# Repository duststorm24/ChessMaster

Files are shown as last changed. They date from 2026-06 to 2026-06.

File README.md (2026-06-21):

# ChessMaster

ChessMaster is a full-stack robotic chess project: a Raspberry Pi camera app for board/piece recognition, a browser-based 3D inverse-kinematics UI for a physical robotic arm, Arduino/CNC-shield firmware for the motors, and CAD files for the printed arm assembly.

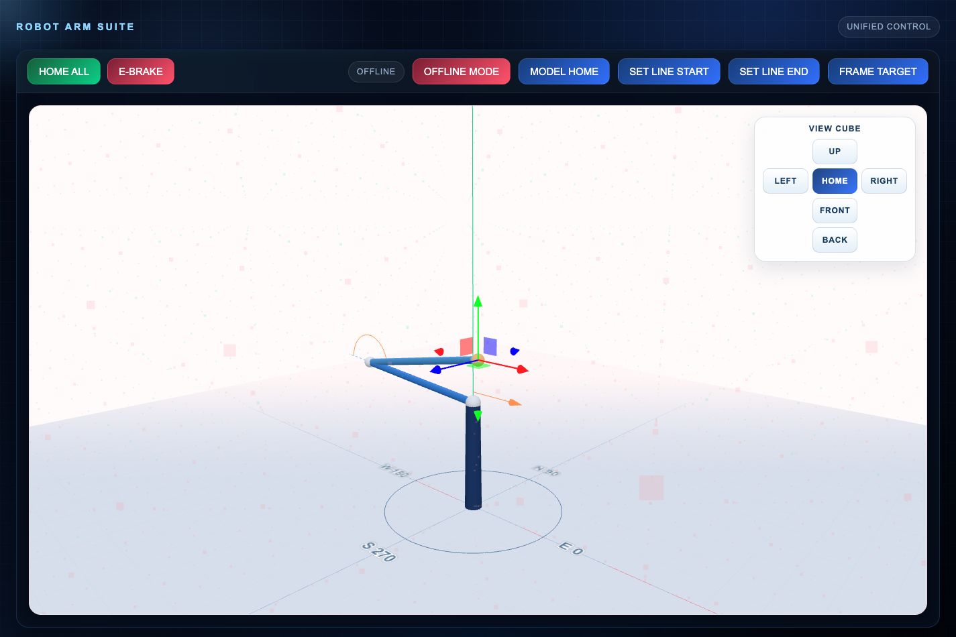
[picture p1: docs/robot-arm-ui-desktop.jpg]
Robot arm 3D UI


<p align="center">
  Robot arm following the 3D inverse-kinematics UI target
</p>

## What This Shows

- **3D robotic arm control:** `apps/robot-web` renders a Three.js arm model with draggable target controls, forward/inverse kinematics, saved positions, and Cartesian line moves.
- **Hardware control path:** the robot UI converts reachable 3D targets into axis step targets and sends them to an Arduino arm controller over serial.
- **Chess vision pipeline:** `apps/vision` runs a Raspberry Pi camera web UI with OpenCV board detection, square crops, calibration, labels, FEN generation, and starter piece-recognition tools.
- **Embedded firmware:** `firmware` contains Arduino/CNC Shield sketches for homing, limit switches, coordinated stepper motion, and serial commands.
- **Physical design:** `hardware/cad` contains STL exports for the arm, base, claw, gears, and chess pieces.

## Project Layout

```text
apps/
  robot-web/      Main 3D IK robotic arm UI and movement API
  vision/         Raspberry Pi camera/CV chessboard app
  arm-ui/         Simpler direct axis/stepper control UI
  arm-test/       Arm test app and matching Arduino sketch
  chessbot-test/  Small chess/Stockfish experiments
firmware/         Arduino and CNC-shield sketches
hardware/cad/     Printable CAD/STL assets
models/           YOLO/model assets used by Pi-side experiments
scripts/          Standalone camera and YOLO stream scripts
data/             Non-secret calibration and saved-position examples
docs/             README images and supporting docs
```

## Main Apps

### 3D Robot Arm UI

```sh
cd apps/robot-web
python3 -m venv .venv
source .venv/bin/activate
pip install -r requirements.txt
python app.py
```

Open `http://localhost:5000`.

The UI can run without the robot attached in offline mode. Online robot movement expects an Arduino-compatible controller at `/dev/ttyACM0`.

### Chess Vision Camera App

```sh
cd apps/vision
python3 -m venv .venv
source .venv/bin/activate
pip install -r requirements.txt
python app.py
```

Open `http://localhost:8000`.

The camera app is intended for Raspberry Pi hardware with a supported camera module. See `apps/vision/README.md` for Pi setup and service installation notes.

## Hardware Notes

The robot control code was built around a Raspberry Pi, Arduino Uno/CNC Shield V3, A4988 stepper drivers, limit switches, and a custom 3-axis printed arm. The web UI and CV app can be inspected without hardware, but real movement/camera capture require the Pi and controller connections.

## Safety And Privacy

This public repo excludes local virtual environments, generated camera captures, logs, caches, `.env` files, and oversized CAD source archives. Non-secret calibration examples and saved robot positions are included so the control and vision workflows are understandable.

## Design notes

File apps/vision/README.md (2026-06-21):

# Chess Vision Camera App

Small Raspberry Pi 5 camera viewer for the first chess-vision milestone.

## Hardware Check

Power the Pi down before connecting the CSI ribbon cable:

```bash
ssh <pi-user>@chesspi.local
cd ~/ChessMaster/apps/vision
./shutdown_for_camera_install.sh --confirm
```

Unplug power, connect the camera to `CAM/DISP0`, reconnect power, then SSH back in.

Verify the camera:

```bash
rpicam-hello --list-cameras
rpicam-still -n -t 2s -o ~/camera-test.jpg
```

Or run the bundled diagnostic check:

```bash
cd ~/ChessMaster/apps/vision
./post_boot_camera_check.sh
```

If the camera is plugged in and still not detected, switch the Pi back to camera auto-detection and reboot:

```bash
cd ~/ChessMaster/apps/vision
./set_camera_autodetect.sh
sudo reboot
```

## Run The Web UI

On the Pi:

```bash
cd ~/ChessMaster/apps/vision
./start.sh
```

To install the web UI as a boot-time service:

```bash
cd ~/ChessMaster/apps/vision
./install_service.sh
```

From your laptop, open:

```text
http://chesspi.local:8000
```

To stop the background server:

```bash
cd ~/ChessMaster/apps/vision
./stop.sh
```

To remove the boot-time service:

```bash
cd ~/ChessMaster/apps/vision
./uninstall_service.sh
```

The UI streams the camera, includes a toggleable chessboard grid overlay, shows camera diagnostics, and saves snapshots into `captures/`. Use the calibration sliders to line the grid up with the board, or point the camera at an empty board and click `Save + detect board` to save a frame, let OpenCV estimate the grid, refresh square crops, and save an annotated board-detection debug image. Set `White at bottom` to match the camera's view. The piece-position editor lets you paint pieces onto squares, save a FEN-backed position, load the standard starting position, or clear the board. The saved-captures gallery lists snapshot images and metadata from the browser, can load saved or predicted labels back into the board painter, apply the current board-painter labels to an existing snapshot, save a labeled training sample in one step, detect the board grid, export each full-board snapshot into 64 labeled square crops under `captures/square-crops/`, and analyze those crops for brightness, contrast, and edge density. The dataset panel plus `/dataset` and `/dataset.csv` endpoints roll analyzed square crops into training-style rows with labels and features. `Train occupancy` builds a simple occupied-vs-empty baseline model, while `Train pieces` builds a starter nearest-centroid image classifier from labeled square crops. `Evaluate pieces` reports training accuracy and leave-one-out accuracy for the labeled crop dataset. `Predict pieces` writes a predicted piece map and FEN back to the capture manifest. `Recognize position` refreshes square crops, predicts pieces, and returns a confidence summary; `Save + recognize` does the same for the live camera frame. Snapshots include a JSON sidecar with the saved calibration, all 64 square rectangles, the saved piece map, and FEN so later chessboard and piece-detection code can map image pixels to squares.

The camera controls include three view modes: `HD 16:9` is a fast cropped preview, `Full FOV` uses the full sensor at `2328 x 1748`, and `Max FOV` uses the full sensor at `4656 x 3496` with a slower 1 FPS stream. Focus controls support continuous autofocus, one-shot autofocus, autofocus range/speed, and manual lens position when the connected camera exposes those controls.

Useful endpoints:

```text
/health
/diagnostics
/readiness
/captures
/dataset
/dataset.csv
/model/occupancy
/model/piece
/model/piece/evaluate
/camera-settings
/focus/trigger
/calibration
/board-map
/position
/snapshot/detect-board
/snapshot/recognize-position
/captures/<snapshot>.jpg/labels
/captures/<snapshot>.jpg/save-labeled-sample
/captures/<snapshot>.jpg/detect-board
/captures/<snapshot>.jpg/predict-pieces
/captures/<snapshot>.jpg/recognize-position
```

`/readiness` rolls camera detection, boot config, captures, calibration, dataset rows, labels, and models into one checklist. If the camera is connected but still not detected, check the boot-config gate and consider `./set_camera_autodetect.sh`.

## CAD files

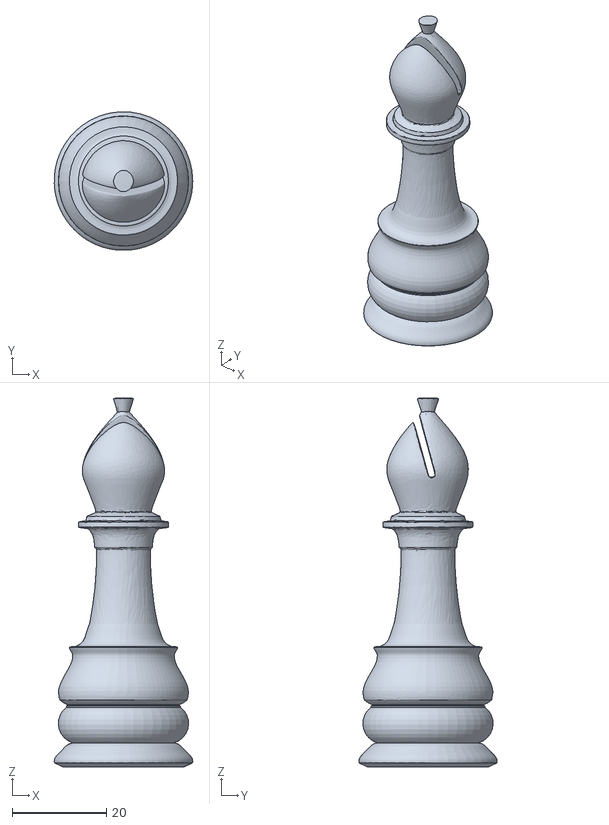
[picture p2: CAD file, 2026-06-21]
hardware/cad/original-cad-files/Chess Pieces/Bishop.stl
29.4 x 29.4 x 78.4

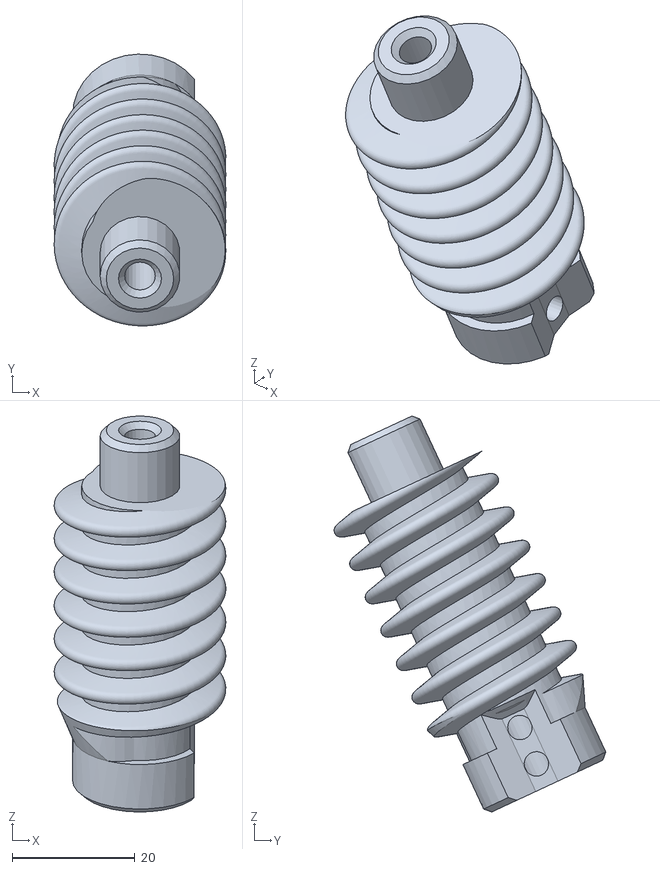
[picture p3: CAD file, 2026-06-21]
hardware/cad/original-cad-files/V3/Chess Playing Robot.stl
28.0 x 44.3 x 64.6

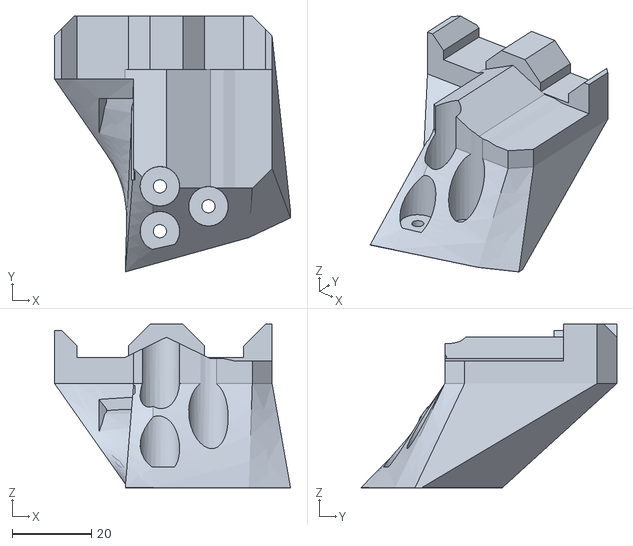
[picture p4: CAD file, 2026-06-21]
hardware/cad/v3-cad-files/V4 Claw Extension.stl
59.6 x 64.7 x 41.4

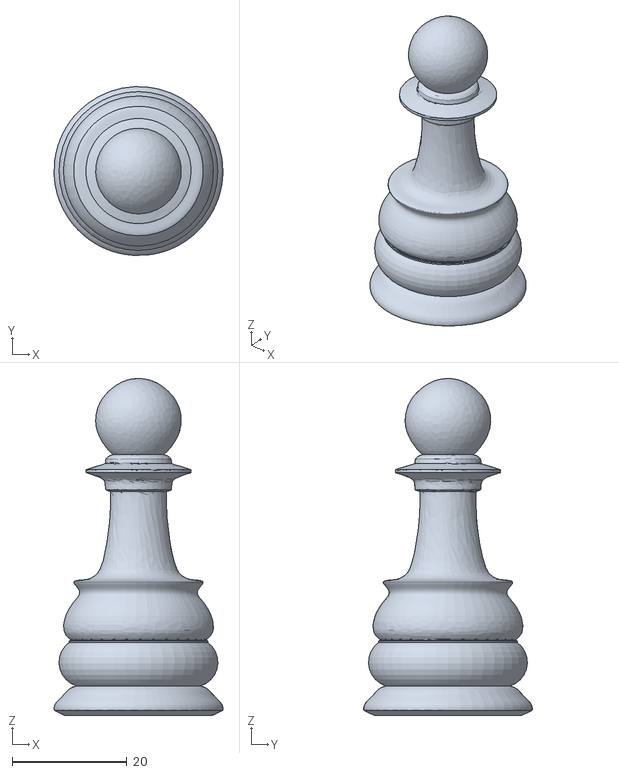
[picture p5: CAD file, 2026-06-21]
hardware/cad/original-cad-files/Chess Pieces/Pawn.stl
29.4 x 29.4 x 58.7

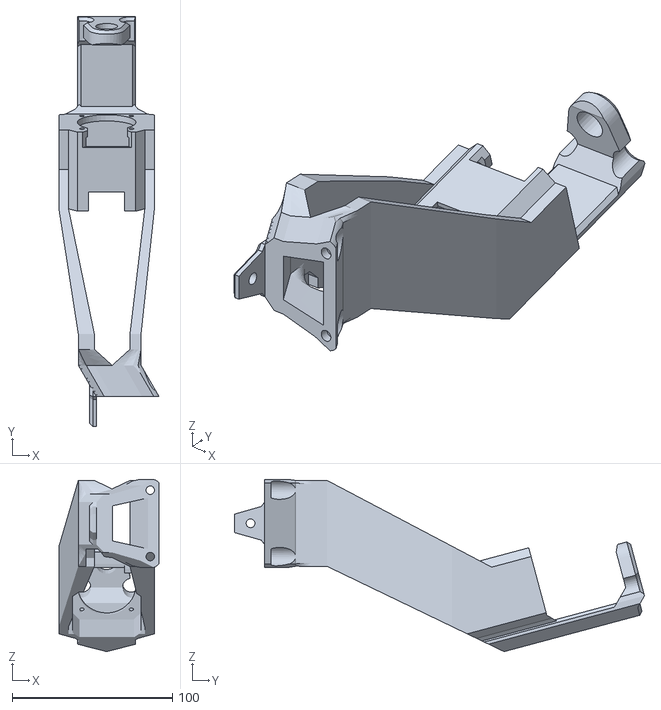
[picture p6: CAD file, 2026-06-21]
hardware/cad/v3-cad-files/Arm 1 Test.stl
62.5 x 255.8 x 107.5

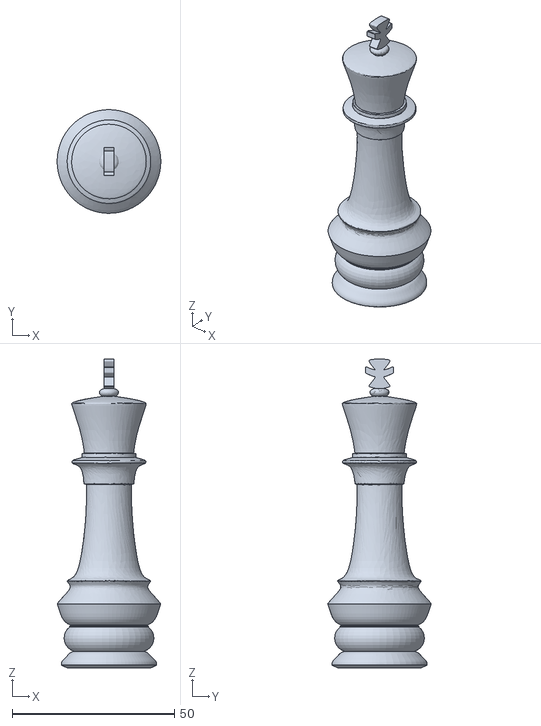
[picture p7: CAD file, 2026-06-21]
hardware/cad/original-cad-files/Chess Pieces/King2.stl
32.0 x 32.0 x 95.3

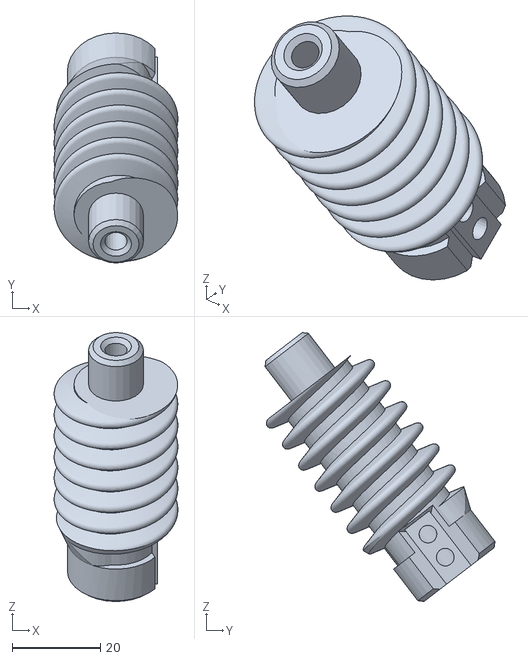
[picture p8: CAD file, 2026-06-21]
hardware/cad/v3-cad-files/V4 Worm Gear.stl
28.0 x 52.0 x 60.8

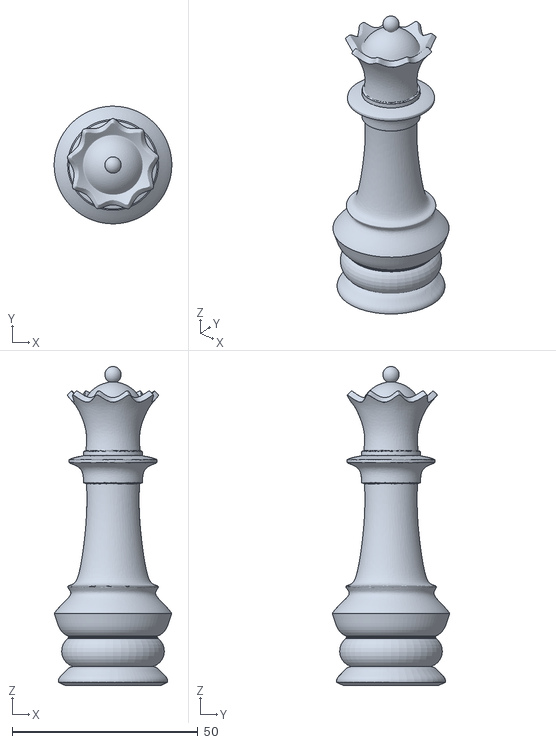
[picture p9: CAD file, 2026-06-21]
hardware/cad/original-cad-files/Chess Pieces/Queen.stl
31.7 x 31.7 x 85.9

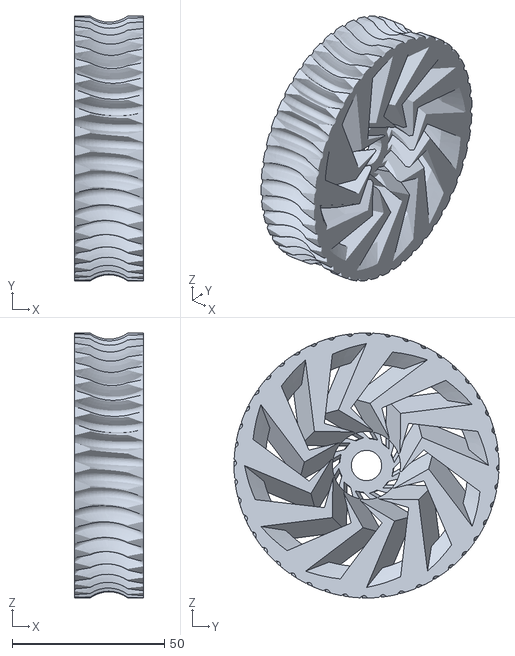
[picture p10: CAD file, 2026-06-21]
hardware/cad/v3-cad-files/Worm Wheel 2.stl
22.7 x 87.0 x 87.0

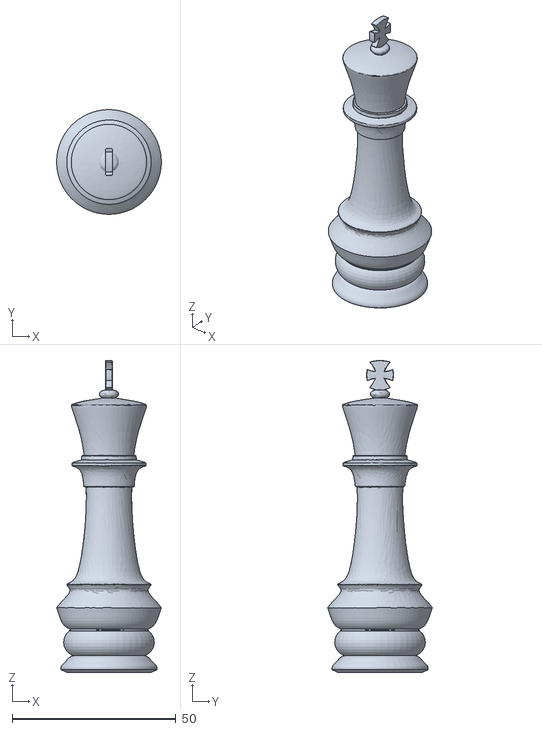
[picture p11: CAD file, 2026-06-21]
hardware/cad/original-cad-files/Chess Pieces/King.stl
32.0 x 32.0 x 95.2

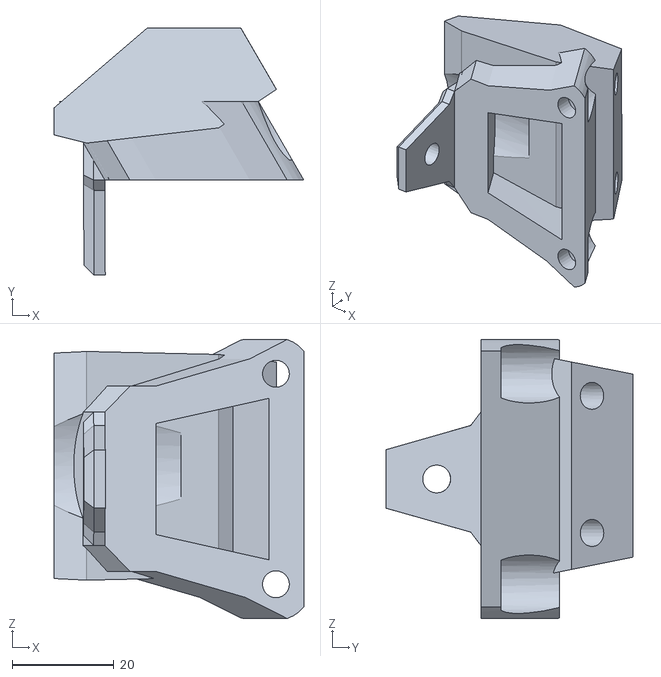
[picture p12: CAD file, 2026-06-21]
hardware/cad/v3-cad-files/Test Adapter.stl
49.2 x 48.7 x 54.9

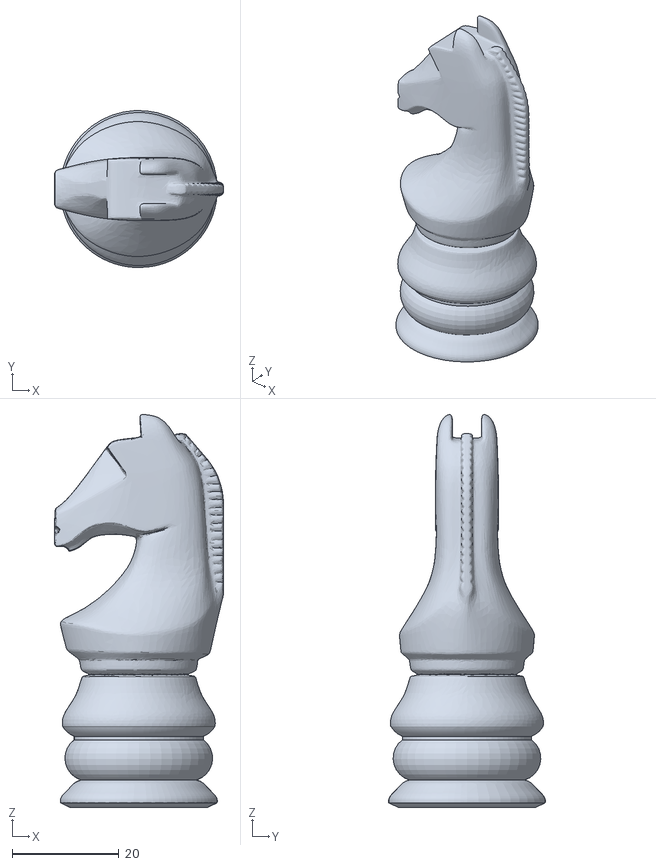
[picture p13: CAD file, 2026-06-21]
hardware/cad/original-cad-files/Chess Pieces/Knight.stl
31.8 x 29.4 x 73.6

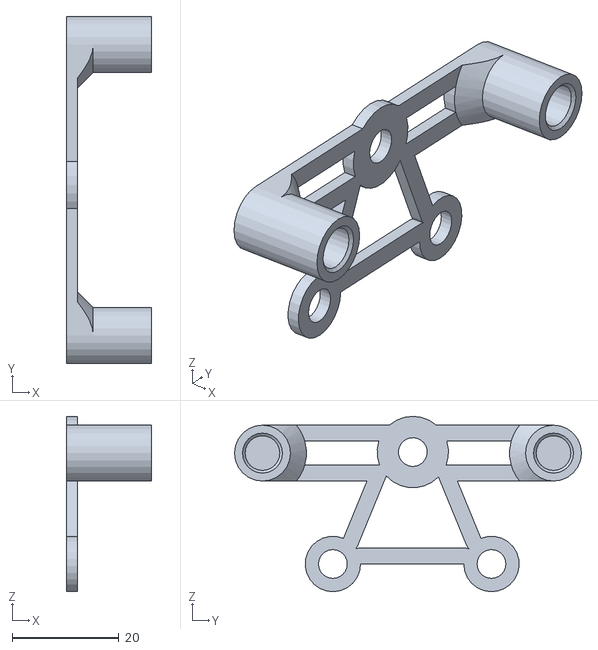
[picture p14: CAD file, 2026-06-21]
hardware/cad/v3-cad-files/Buck Mount 2.stl
15.9 x 65.1 x 32.9

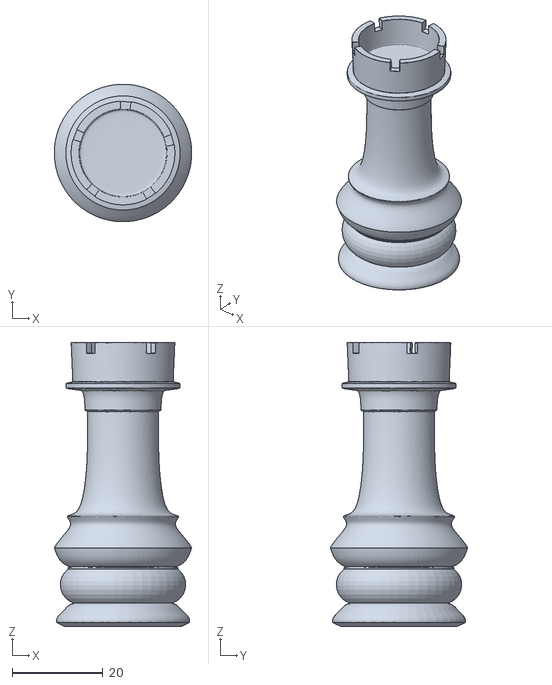
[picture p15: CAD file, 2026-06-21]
hardware/cad/original-cad-files/Chess Pieces/Rook.stl
30.3 x 30.3 x 62.7

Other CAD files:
hardware/cad/v3-cad-files/Worm Wheel.stl
hardware/cad/v3-cad-files/V4 Base.stl
hardware/cad/v3-cad-files/Base Plate V3.stl
hardware/cad/v3-cad-files/Large Claw V3.stl
hardware/cad/original-cad-files/V2/5v Pi Buck Holder.stl
hardware/cad/original-cad-files/V2/ARM1 SMALL.stl
hardware/cad/original-cad-files/V2/Arm 1 Base Backplate.stl
hardware/cad/original-cad-files/V2/Arm 1 Base.stl
hardware/cad/original-cad-files/V2/Arm 1 Stepper Support.stl
hardware/cad/original-cad-files/V2/Arm 1.stl
hardware/cad/original-cad-files/V2/Arm 2 and Stabilizers/Arm 2 Coupler.stl
hardware/cad/original-cad-files/V2/Arm 2 and Stabilizers/Arm 2 Part 1.stl
hardware/cad/original-cad-files/V2/Arm 2 and Stabilizers/Arm 2 Part 2.stl
hardware/cad/original-cad-files/V2/Arm 2 and Stabilizers/Chess Playing Robot.stl
hardware/cad/original-cad-files/V2/Arm 2 and Stabilizers/Coupler.stl
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

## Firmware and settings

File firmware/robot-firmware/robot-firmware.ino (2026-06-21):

#include <AccelStepper.h>

// CNC Shield V3 standard pins for X/Y/Z
#define X_STEP_PIN 2
#define Y_STEP_PIN 3
#define Z_STEP_PIN 4
#define X_DIR_PIN  5
#define Y_DIR_PIN  6
#define Z_DIR_PIN  7
#define ENABLE_PIN 8
#define Z_LIMIT_PIN 11
#define Y_LIMIT_PIN 10
#define X_LIMIT_PIN 9
#define Z_MAX_DISTANCE_FROM_HOME 10000L
#define X_MAX_DISTANCE_FROM_HOME 9000L
#define Y_MAX_DISTANCE_FROM_HOME 9200L
#define X_ACCELERATION 2500.0
#define Y_ACCELERATION 2500.0
#define Z_ACCELERATION 2500.0
#define X_HOME_SPEED 1200
#define Y_HOME_SPEED 1200
#define Z_HOME_SPEED 400
#define MIN_COMMAND_SPEED 25
#define MAX_COMMAND_SPEED 3000
#define KEEP_DRIVERS_ENABLED 0

// A axis on D12/D13 for custom independent control
#define A_STEP_PIN 12
#define A_DIR_PIN  13

AccelStepper stepperX(AccelStepper::DRIVER, X_STEP_PIN, X_DIR_PIN);
AccelStepper stepperY(AccelStepper::DRIVER, Y_STEP_PIN, Y_DIR_PIN);
AccelStepper stepperZ(AccelStepper::DRIVER, Z_STEP_PIN, Z_DIR_PIN);
AccelStepper stepperA(AccelStepper::DRIVER, A_STEP_PIN, A_DIR_PIN);

bool activeX = false;
bool activeY = false;
bool activeZ = false;
bool activeA = false;
bool stepModeX = false;
bool stepModeY = false;
bool stepModeZ = false;
bool stepModeA = false;
bool accelModeX = false;
bool accelModeY = false;
bool accelModeZ = false;
bool homingZ = false;
bool zHomed = false;
bool yHomed = false;
bool xHomed = false;

unsigned long stopTimeX = 0;
unsigned long stopTimeY = 0;
unsigned long stopTimeZ = 0;
unsigned long stopTimeA = 0;

String inputLine = "";

void setDriversEnabled(bool enabled) {
  if (!enabled && KEEP_DRIVERS_ENABLED) {
    enabled = true;
  }
  digitalWrite(ENABLE_PIN, enabled ? LOW : HIGH);
}

bool isZLimitPressed();
bool isYLimitPressed();
bool isXLimitPressed();
long getXDistanceFromHome();
long getYDistanceFromHome();
long getZDistanceFromHome();
bool isYAtOrPastMaxDistance();
bool isZAtOrPastMaxDistance();
int resolveCommandSpeed(int requestedSpeed, int fallbackSpeed);
void startHoming(char axis, int speed);
void startHomingAll(int speedX, int speedY, int speedZ);
void processCommand(String cmd);
bool startAxis(char axis, int speed, int direction, int duration);
void stopAxis(String axis);
void readSerialCommands();
void runMotor(AccelStepper &stepper, bool &active, unsigned long &stopTime);
bool startAxisSteps(char axis, long steps, int direction, int speed);

void setup() {
  Serial.begin(115200);

  pinMode(ENABLE_PIN, OUTPUT);
  setDriversEnabled(KEEP_DRIVERS_ENABLED);
  pinMode(Z_LIMIT_PIN, INPUT_PULLUP);
  pinMode(Y_LIMIT_PIN, INPUT_PULLUP);
  pinMode(X_LIMIT_PIN, INPUT_PULLUP);

  if (isZLimitPressed()) {
    stepperZ.setCurrentPosition(0);
    zHomed = true;
  }
  if (isYLimitPressed()) {
    stepperY.setCurrentPosition(0);
    yHomed = true;
  }
  if (isXLimitPressed()) {
    stepperX.setCurrentPosition(0);
    xHomed = true;
  }

  stepperX.setMaxSpeed(3000);
  stepperY.setMaxSpeed(3000);
  stepperZ.setMaxSpeed(3000);
  stepperA.setMaxSpeed(3000);

  stepperX.setAcceleration(X_ACCELERATION);
  stepperY.setAcceleration(Y_ACCELERATION);
  stepperZ.setAcceleration(Z_ACCELERATION);
  stepperA.setAcceleration(100000);

  stepperX.setSpeed(0);
  stepperY.setSpeed(0);
  stepperZ.setSpeed(0);
  stepperA.setSpeed(0);
}

void loop() {
  readSerialCommands();
  runMotor(stepperX, activeX, stopTimeX);
  runMotor(stepperY, activeY, stopTimeY);
  runMotor(stepperZ, activeZ, stopTimeZ);
  runMotor(stepperA, activeA, stopTimeA);
}

void runMotor(AccelStepper &stepper, bool &active, unsigned long &stopTime) {
  if (!active) {
    return;
  }

  bool isXAxis = (&stepper == &stepperX);
  bool isYAxis = (&stepper == &stepperY);
  bool isZAxis = (&stepper == &stepperZ);

  bool inStepMode = (&stepper == &stepperX && stepModeX) ||
                    (&stepper == &stepperY && stepModeY) ||
                    (&stepper == &stepperZ && stepModeZ) ||
                    (&stepper == &stepperA && stepModeA);
  bool inAccelModeX = isXAxis && accelModeX;
  bool inAccelModeY = isYAxis && accelModeY;
  bool inAccelModeZ = isZAxis && accelModeZ;

  long commandedDelta = 0;
  if (inAccelModeX || inAccelModeY || inAccelModeZ || inStepMode) {
    commandedDelta = stepper.distanceToGo();
  }

  bool movingXTowardHome = isXAxis && ((inAccelModeX || stepModeX) ? (commandedDelta < 0) : (stepper.speed() < 0));
  bool movingXAwayFromHome = isXAxis && ((inAccelModeX || stepModeX) ? (commandedDelta > 0) : (stepper.speed() > 0));
  bool movingYTowardHome = isYAxis && ((inAccelModeY || stepModeY) ? (commandedDelta > 0) : (stepper.speed() > 0));
  bool movingYAwayFromHome = isYAxis && ((inAccelModeY || stepModeY) ? (commandedDelta < 0) : (stepper.speed() < 0));
  bool movingZForward = isZAxis && ((inAccelModeZ || stepModeZ) ? (commandedDelta > 0) : (stepper.speed() > 0));
  bool movingZAwayFromHome = isZAxis && ((inAccelModeZ || stepModeZ) ? (commandedDelta < 0) : (stepper.speed() < 0));

  bool hitXLimit = isXAxis && movingXTowardHome && isXLimitPressed();
  bool hitXMaxDistance = isXAxis && movingXAwayFromHome && xHomed && (stepperX.currentPosition() >= X_MAX_DISTANCE_FROM_HOME);
  bool hitYLimit = isYAxis && movingYTowardHome && isYLimitPressed();
  bool hitYMaxDistance = isYAxis && movingYAwayFromHome && yHomed && (stepperY.currentPosition() <= -Y_MAX_DISTANCE_FROM_HOME);
  bool hitZLimit = isZAxis && movingZForward && isZLimitPressed();
  bool hitZMaxDistance = isZAxis && movingZAwayFromHome && zHomed && (stepperZ.currentPosition() <= -Z_MAX_DISTANCE_FROM_HOME);

  bool timedOut = !(isZAxis && homingZ) && !inStepMode && !inAccelModeX && !inAccelModeY && !inAccelModeZ && (millis() >= stopTime);
  bool reachedTarget = (inStepMode || inAccelModeX || inAccelModeY || inAccelModeZ) && (stepper.distanceToGo() == 0);

  if (hitXLimit) {
    stepper.stop();
    stepper.setSpeed(0);
    active = false;
    stepModeX = false;
    accelModeX = false;
    stepperX.setCurrentPosition(0);
    xHomed = true;

    if (!activeX && !activeY && !activeZ && !activeA) {
      setDriversEnabled(false);
    }
  } else if (hitXMaxDistance) {
    stepper.stop();
    stepper.setSpeed(0);
    active = false;
    stepModeX = false;
    accelModeX = false;
    stepperX.setCurrentPosition(X_MAX_DISTANCE_FROM_HOME);

    if (!activeX && !activeY && !activeZ && !activeA) {
      setDriversEnabled(false);
    }
  } else if (hitYLimit) {
    stepper.stop();
    stepper.setSpeed(0);
    active = false;
    stepModeY = false;
    accelModeY = false;
    stepperY.setCurrentPosition(0);
    yHomed = true;

    if (!activeX && !activeY && !activeZ && !activeA) {
      setDriversEnabled(false);
    }
  } else if (hitYMaxDistance) {
    stepper.stop();
    stepper.setSpeed(0);
    active = false;
    stepModeY = false;
    accelModeY = false;
    stepperY.setCurrentPosition(-Y_MAX_DISTANCE_FROM_HOME);

    if (!activeX && !activeY && !activeZ && !activeA) {
      setDriversEnabled(false);
    }
  } else if (hitZLimit) {
    stepper.stop();
    stepper.setSpeed(0);
    active = false;
    stepperZ.setCurrentPosition(0);
    zHomed = true;
    stepModeZ = false;
    accelModeZ = false;
    homingZ = false;

    if (!activeX && !activeY && !activeZ && !activeA) {
      setDriversEnabled(false);
    }
  } else if (hitZMaxDistance) {
    stepper.stop();
    stepper.setSpeed(0);
    active = false;
    homingZ = false;
    stepModeZ = false;
    accelModeZ = false;
    stepperZ.setCurrentPosition(-Z_MAX_DISTANCE_FROM_HOME);

    if (!activeX && !activeY && !activeZ && !activeA) {
      setDriversEnabled(false);
    }
  } else if (timedOut || reachedTarget) {
    stepper.stop();
    stepper.setSpeed(0);
    active = false;

    if (&stepper == &stepperX) {
      stepModeX = false;
      accelModeX = false;
    }
    if (&stepper == &stepperY) {
      stepModeY = false;
      accelModeY = false;
    }
    if (&stepper == &stepperZ) {
      stepModeZ = false;
      accelModeZ = false;
      homingZ = false;
    }
    if (&stepper == &stepperA) {
      stepModeA = false;
    }

    if (!activeX && !activeY && !activeZ && !activeA) {
      setDriversEnabled(false);
    }
  } else {
    if (inAccelModeX || inAccelModeY || inAccelModeZ) {
      stepper.run();
    } else if (inStepMode) {
      stepper.runSpeedToPosition();
    } else {
      stepper.runSpeed();
    }
  }
}

void readSerialCommands() {
  while (Serial.available()) {
    char c = Serial.read();
    if (c == '\n') {
      processCommand(inputLine);
      inputLine = "";
    } else {
      inputLine += c;
    }
  }
}

bool isYLimitPressed() {
  return digitalRead(Y_LIMIT_PIN) == HIGH;
}

long getYDistanceFromHome() {
  long pos = stepperY.currentPosition();
  return pos >= 0 ? pos : -pos;
}

bool isXLimitPressed() {
  return digitalRead(X_LIMIT_PIN) == HIGH;
}

bool isZLimitPressed() {
  return digitalRead(Z_LIMIT_PIN) == HIGH;
}

long getXDistanceFromHome() {
  long pos = stepperX.currentPosition();
  return pos >= 0 ? pos : -pos;
}

long getZDistanceFromHome() {
  long pos = stepperZ.currentPosition();
  return pos >= 0 ? pos : -pos;
}

bool isZAtOrPastMaxDistance() {
  return zHomed && (getZDistanceFromHome() >= Z_MAX_DISTANCE_FROM_HOME);
}

bool isYAtOrPastMaxDistance() {
  return yHomed && (getYDistanceFromHome() >= Y_MAX_DISTANCE_FROM_HOME);
}

int resolveCommandSpeed(int requestedSpeed, int fallbackSpeed) {
  int safeSpeed = abs(requestedSpeed);
  if (safeSpeed <= 0) {
    safeSpeed = fallbackSpeed;
  }
  if (safeSpeed < MIN_COMMAND_SPEED) {
    safeSpeed = MIN_COMMAND_SPEED;
  }
  if (safeSpeed > MAX_COMMAND_SPEED) {
    safeSpeed = MAX_COMMAND_SPEED;
  }
  return safeSpeed;
}

void startHoming(char axis, int speed) {
  if (axis == 'X') {
    if (isXLimitPressed()) {
      stepperX.stop();
      stepperX.setSpeed(0);
      activeX = false;
      stepModeX = false;
      accelModeX = false;
      stepperX.setCurrentPosition(0);
      xHomed = true;

      if (!activeX && !activeY && !activeZ && !activeA) {
        setDriversEnabled(false);
      }
      Serial.println("OK");
      return;
    }

    setDriversEnabled(true);
    stepperX.setMaxSpeed(resolveCommandSpeed(speed, X_HOME_SPEED));
    stepperX.setAcceleration(X_ACCELERATION);
    stepperX.moveTo(stepperX.currentPosition() - 1000000L);
    activeX = true;
    stepModeX = false;
    accelModeX = true;
    stopTimeX = 4294967295UL;
    Serial.println("OK");
    return;
  }

  if (axis == 'Y') {
    if (isYLimitPressed()) {
      stepperY.stop();
      stepperY.setSpeed(0);
      activeY = false;
      stepModeY = false;
      accelModeY = false;
      stepperY.setCurrentPosition(0);
      yHomed = true;

      if (!activeX && !activeY && !activeZ && !activeA) {
        setDriversEnabled(false);
      }
      Serial.println("OK");
      return;
    }

    setDriversEnabled(true);
    stepperY.setMaxSpeed(resolveCommandSpeed(speed, Y_HOME_SPEED));
    stepperY.setAcceleration(Y_ACCELERATION);
    stepperY.moveTo(stepperY.currentPosition() + 1000000L);
    activeY = true;
    stepModeY = false;
    accelModeY = true;
    stopTimeY = 4294967295UL;
    Serial.println("OK");
    return;
  }

  if (axis != 'Z') {
    Serial.println("ERR");
    return;
  }

  if (isZLimitPressed()) {
    stepperZ.stop();
    stepperZ.setSpeed(0);
    activeZ = false;
    homingZ = false;
    stepModeZ = false;
    accelModeZ = false;
    stepperZ.setCurrentPosition(0);
    zHomed = true;

    if (!activeX && !activeY && !activeZ && !activeA) {
      setDriversEnabled(false);
    }
    Serial.println("OK");
    return;
  }

  setDriversEnabled(true);
  stepperZ.setMaxSpeed(resolveCommandSpeed(speed, Z_HOME_SPEED));
  stepperZ.setAcceleration(Z_ACCELERATION);
  stepperZ.moveTo(stepperZ.currentPosition() + 1000000L);
  activeZ = true;
  homingZ = true;
  stepModeZ = false;
  accelModeZ = true;
  stopTimeZ = 4294967295UL;
  Serial.println("OK");
}

void startHomingAll(int speedX, int speedY, int speedZ) {
  setDriversEnabled(true);

  if (isXLimitPressed()) {
    stepperX.stop();
    stepperX.setSpeed(0);
    activeX = false;
    stepModeX = false;
    accelModeX = false;
    stepperX.setCurrentPosition(0);
    xHomed = true;
  } else {
    stepperX.setMaxSpeed(resolveCommandSpeed(speedX, X_HOME_SPEED));
    stepperX.setAcceleration(X_ACCELERATION);
    stepperX.moveTo(stepperX.currentPosition() - 1000000L);
    activeX = true;
    stepModeX = false;
    accelModeX = true;
    stopTimeX = 4294967295UL;
  }

  if (isYLimitPressed()) {
    stepperY.stop();
    stepperY.setSpeed(0);
    activeY = false;
    stepModeY = false;
    accelModeY = false;
    stepperY.setCurrentPosition(0);
    yHomed = true;
  } else {
    stepperY.setMaxSpeed(resolveCommandSpeed(speedY, Y_HOME_SPEED));
    stepperY.setAcceleration(Y_ACCELERATION);
    stepperY.moveTo(stepperY.currentPosition() + 1000000L);
    activeY = true;
    stepModeY = false;
    accelModeY = true;
    stopTimeY = 4294967295UL;
  }

  if (isZLimitPressed()) {
    stepperZ.stop();
    stepperZ.setSpeed(0);
    activeZ = false;
    homingZ = false;
    stepModeZ = false;
    accelModeZ = false;
    stepperZ.setCurrentPosition(0);
    zHomed = true;
  } else {
    stepperZ.setMaxSpeed(resolveCommandSpeed(speedZ, Z_HOME_SPEED));
    stepperZ.setAcceleration(Z_ACCELERATION);
    stepperZ.moveTo(stepperZ.currentPosition() + 1000000L);
    activeZ = true;
    homingZ = true;
    stepModeZ = false;
    accelModeZ = true;
    stopTimeZ = 4294967295UL;
  }

  if (!activeX && !activeY && !activeZ && !activeA) {
    setDriversEnabled(false);
  }
}

bool startAxisSteps(char axis, long steps, int direction, int speed) {
  long requestedSteps = labs(steps);
  float signedSpeed = abs(speed) * (direction >= 0 ? 1 : -1);

  if (axis == 'X') {
    if (isXLimitPressed()) {
      stepperX.setCurrentPosition(0);
      xHomed = true;

      if (direction < 0) {
        stepperX.setSpeed(0);
        activeX = false;
        stepModeX = false;
        accelModeX = false;

        if (!activeX && !activeY && !activeZ && !activeA) {
          setDriversEnabled(false);
        }
        return false;
      }
    }

    if (!xHomed && direction > 0) {
      return false;
    }

    if (xHomed && direction > 0 && stepperX.currentPosition() >= X_MAX_DISTANCE_FROM_HOME) {
      stepperX.setCurrentPosition(X_MAX_DISTANCE_FROM_HOME);
      stepperX.setSpeed(0);
      activeX = false;
      stepModeX = false;
      accelModeX = false;

      if (!activeX && !activeY && !activeZ && !activeA) {
        setDriversEnabled(false);
      }
      return false;
    }

    setDriversEnabled(true);
    stepperX.setMaxSpeed(abs(speed));
    stepperX.setAcceleration(X_ACCELERATION);

    long targetPos = stepperX.currentPosition() + (direction >= 0 ? requestedSteps : -requestedSteps);
    if (targetPos > X_MAX_DISTANCE_FROM_HOME) {
      targetPos = X_MAX_DISTANCE_FROM_HOME;
    }

    stepperX.moveTo(targetPos);
    stopTimeX = 4294967295UL;
    activeX = true;
    stepModeX = false;
    accelModeX = true;
    return true;
  }

  if (axis == 'Y') {
    if (isYLimitPressed()) {
      stepperY.setCurrentPosition(0);
      yHomed = true;

      if (direction > 0) {
        stepperY.setSpeed(0);
        activeY = false;
        stepModeY = false;
        accelModeY = false;

        if (!activeX && !activeY && !activeZ && !activeA) {
          setDriversEnabled(false);
        }
        return false;
      }
    }

    if (!yHomed && direction < 0) {
      return false;
    }

    if (yHomed && direction < 0 && isYAtOrPastMaxDistance()) {
      stepperY.setCurrentPosition(-Y_MAX_DISTANCE_FROM_HOME);
      stepperY.setSpeed(0);
      activeY = false;
      stepModeY = false;
      accelModeY = false;

      if (!activeX && !activeY && !activeZ && !activeA) {
        setDriversEnabled(false);
      }
      return false;
    }

    setDriversEnabled(true);
    stepperY.setMaxSpeed(abs(speed));
    stepperY.setAcceleration(Y_ACCELERATION);

    long targetPos = stepperY.currentPosition() + (direction >= 0 ? requestedSteps : -requestedSteps);
    if (targetPos > 0) {
      targetPos = 0;
    }
    if (targetPos < -Y_MAX_DISTANCE_FROM_HOME) {
      targetPos = -Y_MAX_DISTANCE_FROM_HOME;
    }

    stepperY.moveTo(targetPos);
    stopTimeY = 4294967295UL;
    activeY = true;
    stepModeY = false;
    accelModeY = true;
    return true;
  }

  if (axis == 'Z') {
    if (isZLimitPressed()) {
      stepperZ.setCurrentPosition(0);
      zHomed = true;

      if (direction >= 0) {
        stepperZ.setSpeed(0);
        activeZ = false;
        homingZ = false;
        stepModeZ = false;
        accelModeZ = false;

        if (!activeX && !activeY && !activeZ && !activeA) {
          setDriversEnabled(false);
        }
        return false;
      }
    }

    if (!zHomed) {
      if (direction < 0) {
        stepperZ.setSpeed(0);
        activeZ = false;
        homingZ = false;
        stepModeZ = false;
        accelModeZ = false;

        if (!activeX && !activeY && !activeZ && !activeA) {
          setDriversEnabled(false);
        }
        return false;
      }
      setDriversEnabled(true);
      stepperZ.setMaxSpeed(abs(speed));
      stepperZ.setAcceleration(Z_ACCELERATION);
      stepperZ.moveTo(stepperZ.currentPosition() + requestedSteps);
      stopTimeZ = 4294967295UL;
      activeZ = true;
      stepModeZ = false;
      accelModeZ = true;
      homingZ = false;
      return true;
    }

    if (direction >= 0) {
      long targetPos = stepperZ.currentPosition() + requestedSteps;
      if (targetPos > 0) {
        targetPos = 0;
      }

      setDriversEnabled(true);
      stepperZ.setMaxSpeed(abs(speed));
      stepperZ.setAcceleration(Z_ACCELERATION);
      stepperZ.moveTo(targetPos);
      stopTimeZ = 4294967295UL;
      activeZ = true;
      stepModeZ = false;
      accelModeZ = true;
      homingZ = false;
      return true;
    } else if (isZAtOrPastMaxDistance()) {
      stepperZ.setCurrentPosition(-Z_MAX_DISTANCE_FROM_HOME);
      stepperZ.setSpeed(0);
      activeZ = false;
      homingZ = false;
      stepModeZ = false;
      accelModeZ = false;

      if (!activeX && !activeY && !activeZ && !activeA) {
        setDriversEnabled(false);
      }
      return false;
    }

    long currentPos = stepperZ.currentPosition();
    long targetPos = currentPos - requestedSteps;
    if (targetPos < -Z_MAX_DISTANCE_FROM_HOME) {
      targetPos = -Z_MAX_DISTANCE_FROM_HOME;
    }

    setDriversEnabled(true);
    stepperZ.setMaxSpeed(abs(speed));
    stepperZ.setAcceleration(Z_ACCELERATION);
    stepperZ.moveTo(targetPos);
    stopTimeZ = 4294967295UL;
    activeZ = true;
    stepModeZ = false;
    accelModeZ = true;
    homingZ = false;
    return true;
  }

  long signedSteps = requestedSteps * (direction >= 0 ? 1L : -1L);

  setDriversEnabled(true);

  switch (axis) {
    case 'A':
      stepperA.setMaxSpeed(abs(speed));
      stepperA.move(signedSteps);
      stepperA.setSpeed(signedSpeed);
      activeA = true;
      stepModeA = true;
      return true;
  }

  if (!activeX && !activeY && !activeZ && !activeA) {
    setDriversEnabled(false);
  }

  return false;
}

void processCommand(String cmd) {
  cmd.trim();

  if (cmd.startsWith("MOVE_STEPS")) {
    char axis;
    long steps;
    int direction;
    int speed;

    int parsed = sscanf(cmd.c_str(), "MOVE_STEPS %c %ld %d %d", &axis, &steps, &direction, &speed);
    if (parsed == 4) {
      Serial.println(startAxisSteps(axis, steps, direction, speed) ? "OK" : "ERR");
    } else {
      Serial.println("ERR");
    }
  } else if (cmd.startsWith("MOVE")) {
    char axis;
    int speed;
    int direction;
    int duration;

    int parsed = sscanf(cmd.c_str(), "MOVE %c %d %d %d", &axis, &speed, &direction, &duration);
    if (parsed == 4) {
      Serial.println(startAxis(axis, speed, direction, duration) ? "OK" : "ERR");
    } else {
      Serial.println("ERR");
    }
  } else if (cmd.startsWith("STOP")) {
    char axis[8];
    int parsed = sscanf(cmd.c_str(), "STOP %7s", axis);
    if (parsed == 1) {
      stopAxis(String(axis));
      Serial.println("OK");
    } else {
      Serial.println("ERR");
    }
  } else if (cmd == "HOME ALL") {
    startHomingAll(0, 0, 0);
    Serial.println("OK");
  } else if (cmd.startsWith("HOME ALL")) {
    int speedX;
    int speedY;
    int speedZ;
    int parsed = sscanf(cmd.c_str(), "HOME ALL %d %d %d", &speedX, &speedY, &speedZ);
    if (parsed == 3) {
      startHomingAll(speedX, speedY, speedZ);
      Serial.println("OK");
    } else {
      Serial.println("ERR");
    }
  } else if (cmd.startsWith("HOME")) {
    char axis;
    int speed;
    int parsed = sscanf(cmd.c_str(), "HOME %c %d", &axis, &speed);
    if (parsed == 2) {
      startHoming(axis, speed);
    } else if (sscanf(cmd.c_str(), "HOME %c", &axis) == 1) {
      startHoming(axis, 0);
    } else {
      Serial.println("ERR");
    }
  } else if (cmd == "STATUS") {
    Serial.print("LIMIT_Z=");
    Serial.println(isZLimitPressed() ? 1 : 0);
  } else if (cmd == "LIMITS") {
    Serial.print("LIMIT_X=");
    Serial.print(isXLimitPressed() ? 1 : 0);
    Serial.print(";");
    Serial.print("LIMIT_Y=");
    Serial.print(isYLimitPressed() ? 1 : 0);
    Serial.print(";");
    Serial.print("LIMIT_Z=");
    Serial.print(isZLimitPressed() ? 1 : 0);
    Serial.print(";");
    Serial.println("LIMIT_A=INACTIVE");
  } else if (cmd == "DIST X") {
    if (xHomed) {
      Serial.print("DIST_X=");
      Serial.println(getXDistanceFromHome());
    } else {
      Serial.println("DIST_X=UNKNOWN");
    }
  } else if (cmd == "DIST Y") {
    if (yHomed) {
      Serial.print("DIST_Y=");
      Serial.println(getYDistanceFromHome());
    } else {
      Serial.println("DIST_Y=UNKNOWN");
    }
  } else if (cmd == "DIST Z") {
    if (zHomed) {
      Serial.print("DIST_Z=");
      Serial.println(getZDistanceFromHome());
    } else {
      Serial.println("DIST_Z=UNKNOWN");
    }
  } else {
    Serial.println("ERR");
  }
}
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

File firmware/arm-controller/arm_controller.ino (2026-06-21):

// === Chess Robot Arm – 3 Steppers + Limit Switches ===
// Control via Serial from the Raspberry Pi.
//
// Hardware mapping (CNC Shield V3 + Arduino Uno):
//   Stepper 1 (base rotation)  -> X driver  (STEP=2, DIR=5)
//   Stepper 2 (first arm)      -> Z driver  (STEP=4, DIR=7)
//   Stepper 3 (second arm)     -> Y driver  (STEP=3, DIR=6)
//
//   Limit switches wired to "X-", "Y-", "Z-" on the shield.
//   Typical CNC Shield v3 mapping (adjust if yours differs):
//     X- -> D9
//     Y- -> D11
//     Z- -> D13
//
//   Limit switches are assumed wired: pin --- switch --- GND
//   with internal pullups enabled (normal = HIGH, pressed = LOW).
//
// Serial protocol (from Pi or Serial Monitor):
//
//   H1        -> home stepper 1 (toward its limit switch)
//   H2        -> home stepper 2
//   H3        -> home stepper 3
//   HA        -> home ALL 3, one after another
//
//   M1 1000   -> move stepper 1 by +1000 steps
//   M2 -500   -> move stepper 2 by -500 steps
//   M3 200    -> move stepper 3 by +200 steps
//
//   V 800 600 400  -> set speed (steps/sec) for stepper1/2/3
//
//   Q         -> query status; prints one line:
//                POS 1:<p1> 2:<p2> 3:<p3> LIM X:<lx> Y:<ly> Z:<lz>
//
// Notes about homing directions (based on your description):
//   - Stepper 1: negative direction moves TOWARD its limit -> homeDir = -1
//   - Stepper 2: negative direction moves TOWARD its limit -> homeDir = -1
//   - Stepper 3: positive direction moves TOWARD its limit -> homeDir = +1
//
// You can tweak homeDir or pin numbers later if directions are flipped.

const int EN_PIN  = 8;   // Enable (LOW = enable, HIGH = disable) on most CNC shields

// STEP/DIR pins (CNC Shield defaults)
const int X_STEP = 2;
const int X_DIR  = 5;

const int Y_STEP = 3;
const int Y_DIR  = 6;

const int Z_STEP = 4;
const int Z_DIR  = 7;

// Limit switch pins – adjust if your shield is different
const int LIMIT_X_PIN = 9;   // X- endstop
const int LIMIT_Y_PIN = 11;  // Y- endstop
const int LIMIT_Z_PIN = 13;  // Z- endstop

// Homing safety cap: never step more than this while searching for a switch
const long MAX_HOMING_STEPS = 20000L;

// Default speeds (steps per second)
long speed1_sps = 800;
long speed2_sps = 800;
long speed3_sps = 800;

const long MIN_SPEED_SPS = 50;
const long MAX_SPEED_SPS = 4000;

bool estop = false;  // future use if you want an E-stop serial command

struct Axis {
  int stepPin;
  int dirPin;
  int limitPin;
  long position;   // steps from home (0 after homing)
  int homeDir;     // +1 or -1
  long speed_sps;  // current speed for this axis
};

// Mapping physical axes to drivers & limits:
//
// Axis 1 -> Stepper 1: base, X driver, X- limit
// Axis 2 -> Stepper 2: first arm, Z driver, Z- limit
// Axis 3 -> Stepper 3: second arm, Y driver, Y- limit
Axis axis1 = { X_STEP, X_DIR, LIMIT_X_PIN, 0L, -1, 800 };
Axis axis2 = { Z_STEP, Z_DIR, LIMIT_Z_PIN, 0L, -1, 800 };
Axis axis3 = { Y_STEP, Y_DIR, LIMIT_Y_PIN, 0L, +1, 800 };

void setupAxisPins(Axis &ax) {
  pinMode(ax.stepPin, OUTPUT);
  pinMode(ax.dirPin, OUTPUT);
  digitalWrite(ax.stepPin, LOW);
}

bool isLimitPressed(const Axis &ax) {
  // LOW == pressed if using INPUT_PULLUP
  return digitalRead(ax.limitPin) == LOW;
}

void stepOnce(Axis &ax, int dir) {
  digitalWrite(ax.dirPin, (dir > 0) ? HIGH : LOW);

  digitalWrite(ax.stepPin, HIGH);
  delayMicroseconds(3);
  digitalWrite(ax.stepPin, LOW);

  long speed_sps = ax.speed_sps;
  if (speed_sps < MIN_SPEED_SPS) speed_sps = MIN_SPEED_SPS;
  if (speed_sps > MAX_SPEED_SPS) speed_sps = MAX_SPEED_SPS;

  unsigned long interval_us = 1000000UL / (unsigned long)speed_sps;
  delayMicroseconds(interval_us);

  ax.position += (dir > 0) ? 1 : -1;
}

void homeAxis(Axis &ax, const char *label) {
  Serial.print("[HOME] Axis ");
  Serial.println(label);

  // If already pressed at startup, treat as home
  if (isLimitPressed(ax)) {
    ax.position = 0;
    Serial.print("[HOME] Axis ");
    Serial.print(label);
    Serial.println(" already at home (switch pressed).");
    return;
  }

  long steps = 0;
  while (!isLimitPressed(ax) && steps < MAX_HOMING_STEPS && !estop) {
    stepOnce(ax, ax.homeDir);
    steps++;
  }

  if (isLimitPressed(ax)) {
    ax.position = 0;
    Serial.print("[HOME] Axis ");
    Serial.print(label);
    Serial.print(" homed in ");
    Serial.print(steps);
    Serial.println(" steps.");
  } else {
    Serial.print("[HOME] Axis ");
    Serial.print(label);
    Serial.println(" failed (switch not hit).");
  }
}

void moveAxisSteps(Axis &ax, long steps, const char *label) {
  if (steps == 0) return;

  int dir = (steps > 0) ? +1 : -1;
  long remaining = (steps > 0) ? steps : -steps;

  Serial.print("[MOVE] Axis ");
  Serial.print(label);
  Serial.print(" steps=");
  Serial.println(steps);

  while (remaining > 0 && !estop) {
    // Optional: if moving toward the switch and it's already pressed, stop
    if ((dir == ax.homeDir) && isLimitPressed(ax)) {
      Serial.print("[MOVE] Axis ");
      Serial.print(label);
      Serial.println(" hit limit during move.");
      break;
    }

    stepOnce(ax, dir);
    remaining--;
  }
}

void printStatus() {
  int lx = isLimitPressed(axis1) ? 1 : 0;
  int ly = isLimitPressed(axis3) ? 1 : 0; // axis3 uses Y limit
  int lz = isLimitPressed(axis2) ? 1 : 0; // axis2 uses Z limit

  Serial.print("POS 1:");
  Serial.print(axis1.position);
  Serial.print(" 2:");
  Serial.print(axis2.position);
  Serial.print(" 3:");
  Serial.print(axis3.position);
  Serial.print(" LIM X:");
  Serial.print(lx);
  Serial.print(" Y:");
  Serial.print(ly);
  Serial.print(" Z:");
  Serial.println(lz);
}

void setup() {
  Serial.begin(115200);

  pinMode(EN_PIN, OUTPUT);
  digitalWrite(EN_PIN, LOW);    // enable all drivers

  // Limit pins with pullups
  pinMode(LIMIT_X_PIN, INPUT_PULLUP);
  pinMode(LIMIT_Y_PIN, INPUT_PULLUP);
  pinMode(LIMIT_Z_PIN, INPUT_PULLUP);

  setupAxisPins(axis1);
  setupAxisPins(axis2);
  setupAxisPins(axis3);

  Serial.println("=== Chess Robot 3-axis controller (Arduino) ===");
  Serial.println("Commands:");
  Serial.println("  H1 / H2 / H3 / HA");
  Serial.println("  M1 <steps> / M2 <steps> / M3 <steps>");
  Serial.println("  V <s1> <s2> <s3>   (steps/sec)");
  Serial.println("  Q   (query status)");
}
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

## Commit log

2026-06-21 Initial public release
    [5v Pi Buck Holder.stl, ARM1 SMALL.stl, Arm 1 Base Backplate.stl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]
2026-06-21 Add robot arm demo GIF to README
